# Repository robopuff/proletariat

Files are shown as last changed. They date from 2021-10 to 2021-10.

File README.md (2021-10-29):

# Proletariat

Easy to build, pro-micro (nice!nano for bluetooth) through the hole
numpad/macropad with rotary encoders and 0.91" OLED support.




## Required components

- 24 or 25x 1N4148 axial diodes
  - 25 if battery pack and on/off switch included
- 1x tactile switch (reset)
- 1x slide switch (on/off, 450302014072-ND recommended)
- Battery holder and 3.3V rechargable battery
- 2xEC12/EC16 Rotary Encoders with knobs (Kilo International for the ultimate look and feel)
- Pro Micro compatible MCU
  - For BT use nice!nano
  - For anything else, do not connect battery pack, or check pinouts for further compatibility
- One or none of the supported OLED screens
  - 0.91" SSD1306 I2C OLED
- 27x  Kailh hot swappable sockets
- 24x MX-compatible switches & keycaps
  - Supports 3x2u

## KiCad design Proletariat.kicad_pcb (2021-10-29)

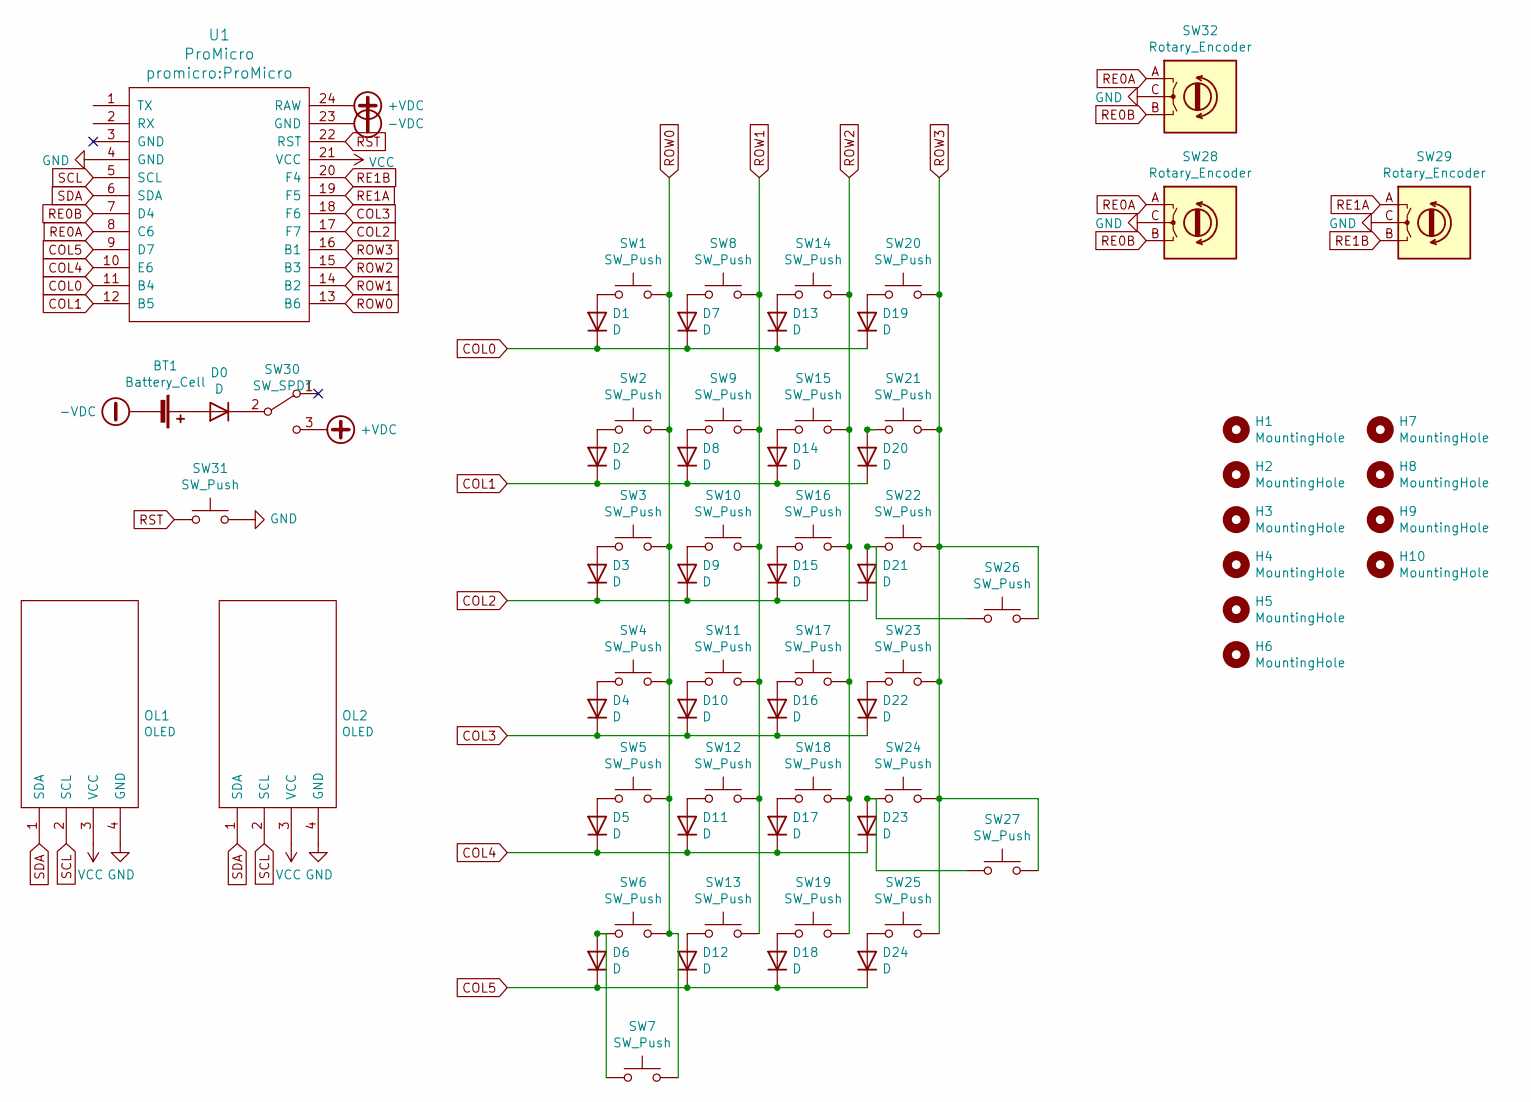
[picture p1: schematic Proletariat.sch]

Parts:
BT1: Battery_Cell; BatteryHolder_MPD_BH-18650-PC2
D0, D1, D2, D3, D4, D5, D6, D7, D8, D9, D10, D11, D12, D13, D14, D15, D16, D17, D18, D19, D20, D21, D22, D23, D24: D; Diode_keyboard
H1, H2, H3, H4, H5, H6, H7, H8, H9, H10: MountingHole; Generic-Mounthole
OL1, OL2: OLED; OLED_v2
SW1, SW2, SW3, SW4, SW5, SW6, SW8, SW9, SW10, SW11, SW12, SW13, SW14, SW15, SW16, SW17, SW18, SW19, SW20, SW21, SW22, SW23, SW24, SW25: SW_Push; SW_Hotswap_Kailh_1.00u
SW7: SW_Push; SW_Hotswap_Kailh_2.00u
SW26, SW27: SW_Push; SW_Hotswap_Kailh_2.00u_Rotated
SW28, SW29: Rotary_Encoder; RotaryEncoder_Alps_EC12E_Vertical_H20mm
SW30: SW_SPDT; SW_SLIDE_SPDT_HORIZONTAL; Part Wurth Elektronik 450301014042; DigiKey 450301014042-ND
SW31: SW_Push; SW_PUSH_6mm_H4.3mm
SW32: Rotary_Encoder; RotaryEncoder_Alps_EC12E_Vertical_H20mm_CircularMountingHol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
U1: ProMicro

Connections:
+VDC: SW30.3 (C), U1.24 (RAW)
-VDC: BT1.2 (-), U1.23 (GND)
COL0: D1.1 (K), D7.1 (K), D13.1 (K), D19.1 (K), U1.11 (B4)
COL1: D2.1 (K), D8.1 (K), D14.1 (K), D20.1 (K), U1.12 (B5)
COL2: D3.1 (K), D9.1 (K), D15.1 (K), D21.1 (K), U1.17 (F7)
COL3: D4.1 (K), D10.1 (K), D16.1 (K), D22.1 (K), U1.18 (F6)
COL4: D5.1 (K), D11.1 (K), D17.1 (K), D23.1 (K), U1.10 (E6)
COL5: D6.1 (K), D12.1 (K), D18.1 (K), D24.1 (K), U1.9 (D7)
GND: OL1.4 (GND), OL2.4 (GND), SW28.C, SW29.C, SW31.2, SW32.C, U1.4 (GND)
unnamed: BT1.1 (+), D0.2 (A)
unnamed: D0.1 (K), SW30.2 (B)
unnamed: D1.2 (A), SW1.1
unnamed: D2.2 (A), SW2.1
unnamed: D3.2 (A), SW3.1
unnamed: D4.2 (A), SW4.1
unnamed: D5.2 (A), SW5.1
unnamed: D6.2 (A), SW6.1, SW7.1
unnamed: D7.2 (A), SW8.1
unnamed: D8.2 (A), SW9.1
unnamed: D9.2 (A), SW10.1
unnamed: D10.2 (A), SW11.1
unnamed: D11.2 (A), SW12.1
unnamed: D12.2 (A), SW13.1
unnamed: D13.2 (A), SW14.1
unnamed: D14.2 (A), SW15.1
unnamed: D15.2 (A), SW16.1
unnamed: D16.2 (A), SW17.1
unnamed: D17.2 (A), SW18.1
unnamed: D18.2 (A), SW19.1
unnamed: D19.2 (A), SW20.1
unnamed: D20.2 (A), SW21.1
unnamed: D21.2 (A), SW22.1, SW26.1
unnamed: D22.2 (A), SW23.1
unnamed: D23.2 (A), SW24.1, SW27.1
unnamed: D24.2 (A), SW25.1
RE0A: SW28.A, SW32.A, U1.8 (C6)
RE0B: SW28.B, SW32.B, U1.7 (D4)
RE1A: SW29.A, U1.19 (F5)
RE1B: SW29.B, U1.20 (F4)
ROW0: SW1.2, SW2.2, SW3.2, SW4.2, SW5.2, SW6.2, SW7.2, U1.13 (B6)
ROW1: SW8.2, SW9.2, SW10.2, SW11.2, SW12.2, SW13.2, U1.14 (B2)
ROW2: SW14.2, SW15.2, SW16.2, SW17.2, SW18.2, SW19.2, U1.15 (B3)
ROW3: SW20.2, SW21.2, SW22.2, SW23.2, SW24.2, SW25.2, SW26.2, SW27.2, U1.16 (B1)
RST: SW31.1, U1.22 (RST)
SCL: OL1.2 (SCL), OL2.2 (SCL), U1.5 (SCL)
SDA: OL1.1 (SDA), OL2.1 (SDA), U1.6 (SDA)
VCC: OL1.3 (VCC), OL2.3 (VCC), U1.21 (VCC)

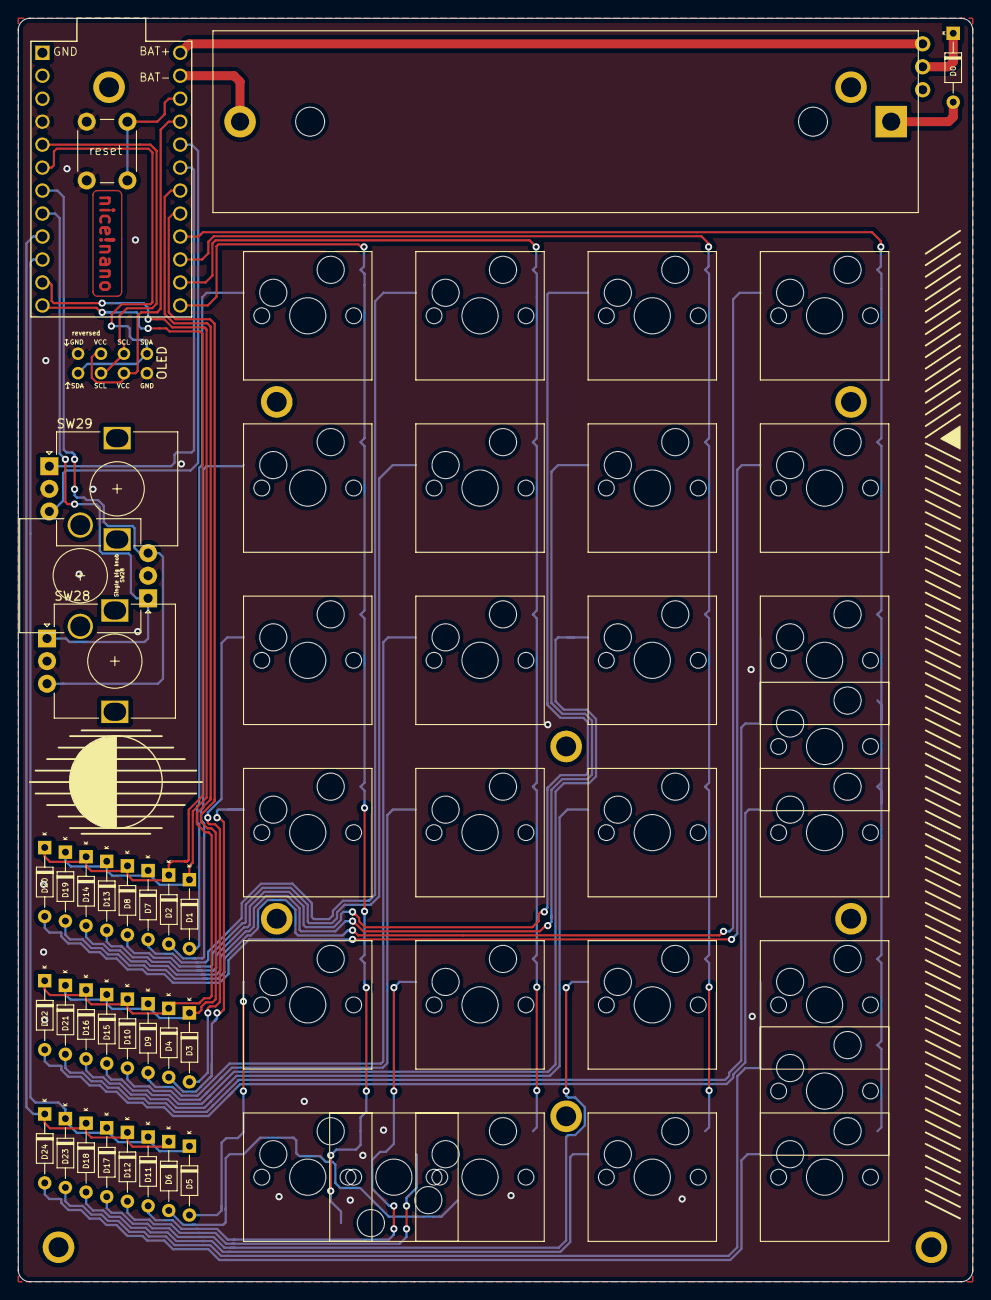
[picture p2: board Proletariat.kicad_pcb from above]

Board: 2 copper layers, 105.5 x 139.7 mm, 71 parts (1 on the bottom side), 47 nets.

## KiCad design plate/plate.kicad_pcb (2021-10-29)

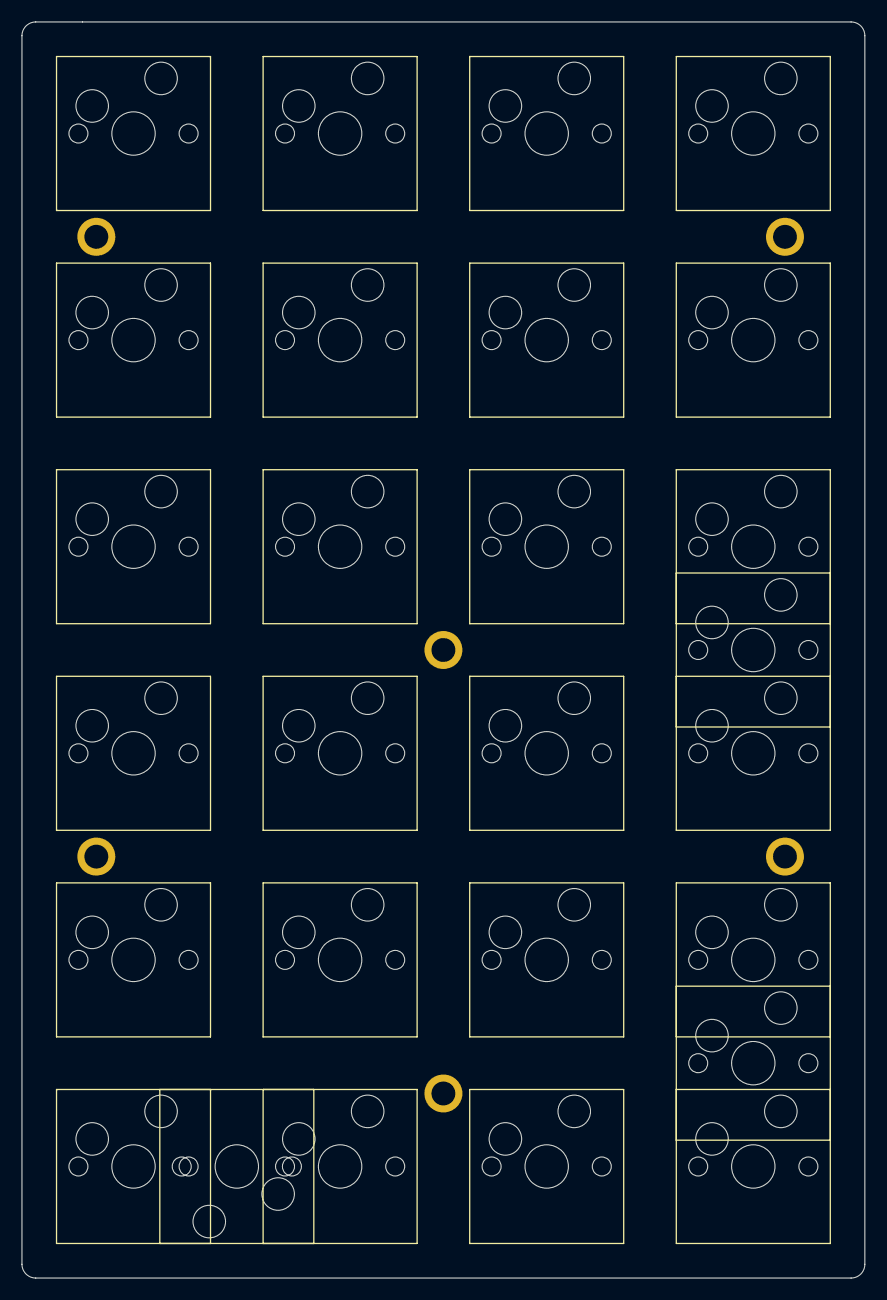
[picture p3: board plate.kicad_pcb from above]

Board: 2 copper layers, 77.7 x 115.8 mm, 33 parts (0 on the bottom side), 7 nets, no tracks yet.

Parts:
H2, H5, H7, H8, H9, H10: MountingHole; Generic-Mounthole
SW1, SW2, SW3, SW4, SW5, SW6, SW8, SW9, SW10, SW11, SW12, SW13, SW14, SW15, SW16, SW17, SW18, SW19, SW20, SW21, SW22, SW23, SW24, SW25: SW_Push; SW_Hotswap_Kailh_1.00u
SW7: SW_Push; SW_Hotswap_Kailh_2.00u
SW26, SW27: SW_Push; SW_Hotswap_Kailh_2.00u_Rotated

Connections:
unnamed: SW6.1, SW7.1
unnamed: SW22.1, SW26.1
unnamed: SW24.1, SW27.1
ROW0: SW1.2, SW2.2, SW3.2, SW4.2, SW5.2, SW6.2, SW7.2
ROW1: SW8.2, SW9.2, SW10.2, SW11.2, SW12.2, SW13.2
ROW2: SW14.2, SW15.2, SW16.2, SW17.2, SW18.2, SW19.2
ROW3: SW20.2, SW21.2, SW22.2, SW23.2, SW24.2, SW25.2, SW26.2, SW27.2

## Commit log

2021-10-29 first version
    [Proletariat-B_Cu.gbr, Proletariat-B_Mask.gbr, Proletariat-B_Paste.gbr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]
2021-10-29 remove unnecessary gerber zip files
